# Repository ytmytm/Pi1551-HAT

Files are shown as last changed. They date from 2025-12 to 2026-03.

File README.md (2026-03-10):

# PI1551 HAT

A minimalistic HAT for Raspberry Pi 3A/3B/3B+ that gives you low-cost **1551 floppy emulation** (and optionally **TAP tape playback**) for Commodore C16/C116 or Plus/4. You build only what you need: the core is a few parts; display, controls, and TAP support are optional add-ons.

**Warning: For [tcbm2sd](https://github.com/ytmytm/plus4-tcbm2sd) ONLY. Do not connect this HAT to a real 1551 drive. The circuit is not 5V-tolerant and can damage the Raspberry Pi.**

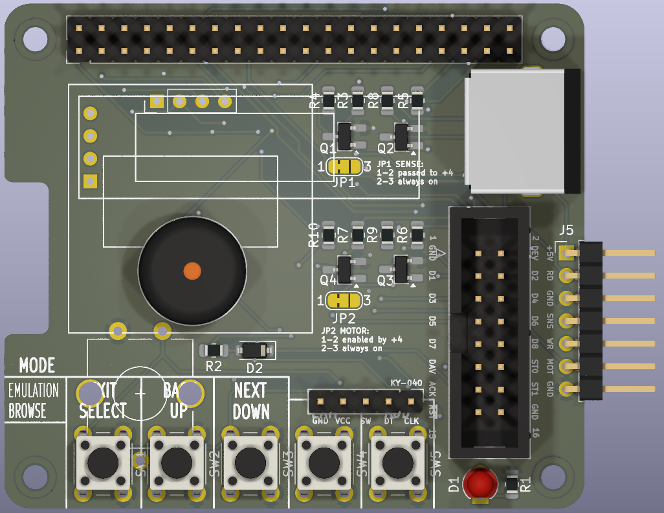
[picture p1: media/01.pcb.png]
PI1551 HAT PCB


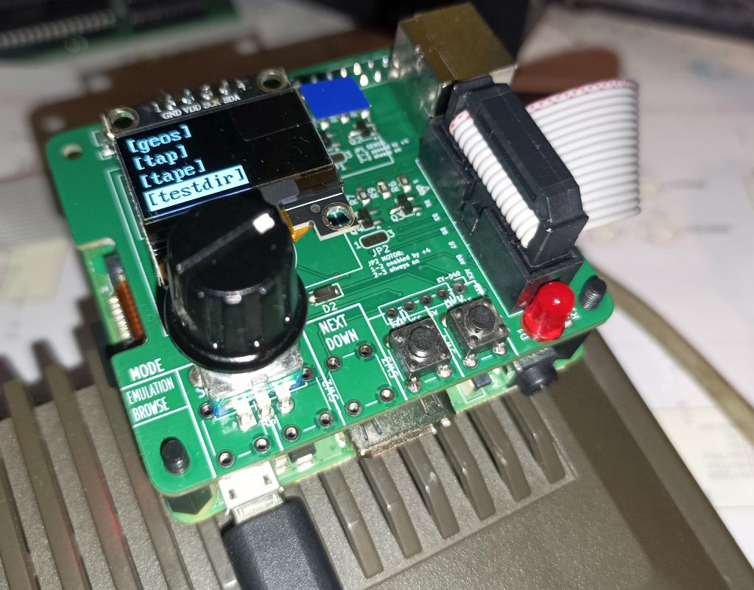
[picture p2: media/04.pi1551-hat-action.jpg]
PI1551-HAT in action


---

## What to build (at a glance)

This is a HAT board that sits on top of a Raspberry Pi. You need to have a Raspberry Pi 3A or 3B and a capable (at least 2A) USB-Micro power supplier for it.

| Goal | You need |
|---|---|
| **1551 emulation only** | PCB + required parts below + 16-wire ribbon cable + [tcbm2sd](https://github.com/ytmytm/plus4-tcbm2sd). No display, no buttons (disk commands only or HDMI+USB keyboard). |
| **1551 + menu on device** | Above + **one of**: 5 buttons, or 2 buttons + rotary encoder (ALPS EC11E or KY-040). Optionally add OLED and/or LED. |
| **1551 + TAP playback** | Above + TAP_READ block (Q2, R5, R8) + MiniDIN-7 socket or J5 header + cable to computer. Rest of TAP circuit is optional but recommended (see [TAP playback](#tap-playback)). |

Everything not in the “required parts” list is optional. You can add options later.

---

## Origin

Cloned from [PI1541 Hat](https://github.com/tebl/C64-Pi1541-module), adapted for 1551 and tape playback.

## Software

Firmware: [Pi1551](https://github.com/ytmytm/Pi1551) (branch `pi1551`).

## Hardware

The [Releases](https://github.com/ytmytm/Pi1551-HAT/releases) section contains all the files you need for manufacturing the PCB with SMD parts populated. That includes Gerber files, BOM with JLCPCB part numbers and SMD part positions.

- [Schematic PDF](plots/RPi_Hat.pdf)
- [Gerbers](plots/)

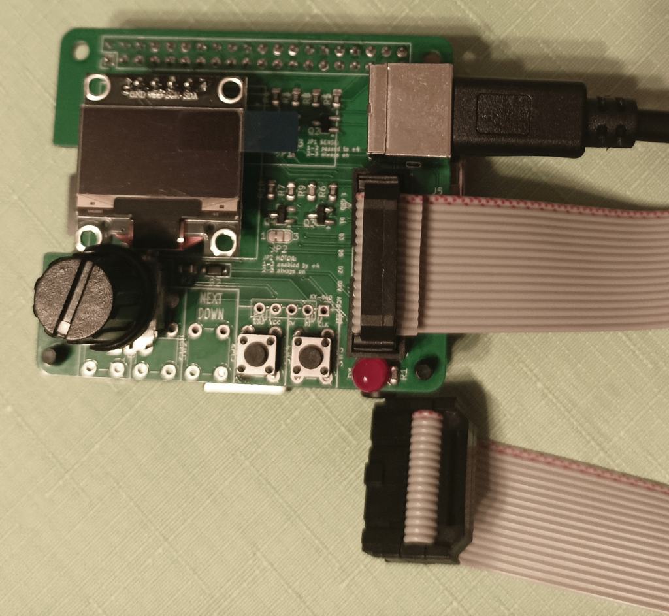
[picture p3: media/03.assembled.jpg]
PI1551 HAT fully assembled


### Required parts (1551 emulation)

- 40×2 female header for Raspberry Pi GPIO
- 2×8 (16-pin) male IDC connector for ribbon cable to [tcbm2sd](https://github.com/ytmytm/plus4-tcbm2sd)
- D2: Schottky diode (BAT54, BAS40, BAT43 or 1N5819) — protects the Pi
- R2: 10K resistor (with D2)
- R11-23: 13×10K resistors (TCBM pullups)

Plus a **straight 16-wire ribbon cable**. Connections are 1:1; both ends must be crimped the same way. I recommend crimping the cable the same way as in the photo above, with both connectors identical — it makes cable routing easier on both ends.

You can order the PCB with SMD parts pre-populated:

<a href="https://www.pcbway.com/project/shareproject/PI1551_HAT_a7817d89.html">PCB from PCBWay</a>

### Optional: display

- OLED: SSD1306 128×64 or 128×32, or SH1106 128×64 (SH1106 is large - there is no room for rotary encoder, use 5 buttons instead).
- Pinout selectable by solder jumpers: GND/VCC/SCL/SCL (default) or VCC/GND/SCL/SCL.

### Optional: drive LED

- 3 mm or 5 mm LED + R1 (e.g. 220 Ω).

### Optional: audio

- 3 V buzzer with built-in oscillator.

### Optional: controls (pick one set)

- **Option A:** 5× 6×6 mm tact switches (SW1–SW5).
- **Option B:** 2× 6×6 mm tact switches (SW4-SW5) + rotary encoder (ALPS EC11E or a KY-040 module).

### TAP playback

To play TAP files you need:

- **TAP_READ block:** Q2, R5, R8 (required for tape in).
- **Connector:** MiniDIN-7 socket (J4) **or** 1×7 pin header (J5) to solder the cable.
- **Cable:** At least TAP_READ and GND; one end must be Mini-DIN-7 male.

A MiniDin-7 cable from Aliexpress may not fit Plus/4 cassette port because the squared plug won't fit the round hole in Plus/4 case. Just shave off the corners to make it more round. It may not look pretty, but it will work. 

If you intend to solder the cable yourself, the order of signals on J5 is such that it's easy to solder a piece of ribbon cable to a Mini-DIN-7 plug by going around the perimeter (see schematic for both pinouts). 

The rest of the TAP circuit is optional, but recommended:

- **TAP_SENSE** (Q1, R3, R4): lets the computer see “tape PLAY pressed”. If you omit it, close jumper JP1 so SENSE is always active.
- **MOTOR** (Q4, R7, R10): lets the computer control motor line. If you omit it, close JP2 so motor is always enabled (fine for Pi1551).

You can also leave all parts in and configure behaviour in the [Pi1551](https://github.com/ytmytm/Pi1551) config.

*If your Plus/4 has a 6510 CPU swap, it cannot drive the MOTOR line (see [this note](https://hackjunk.com/2017/06/23/commodore-16-plus-4-8501-to-6510-cpu-conversion/)). You can still have MOTOR active all the time via the [Pi1551](https://github.com/ytmytm/Pi1551) configuration file.*

**TAP_WRITE** (Q3, R6, R9) is on the PCB for future use when Pi1551 supports tape write.

## PCB

The board is a mixture of THT and SMD parts.

Don't be afraid of SMD parts, I have used larger footprints that are more friendly for hand soldering. You need tweezers, a steady hand, iron with a fine tip and a 0.5mm solder. Use the flux generously.

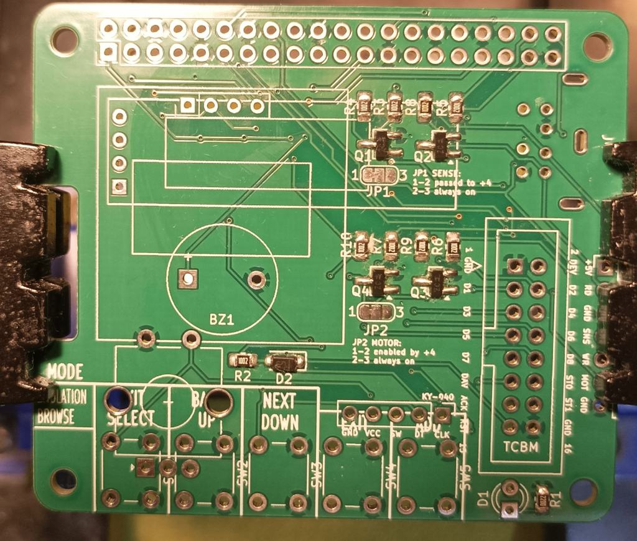
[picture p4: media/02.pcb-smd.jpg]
PI1551 HAT PCB with SMD parts assembled


Note the D2 diode orientation - the stripe is on the same side as the closed silkscreen, towards the TCBM connector. 

For convenience, the majority of resistors (R2-R23) are all the same. Use any value in the 1K-10K range you have at hand.

You might find that soldering those four SMD transistors, ten resistors and one diode is faster than their THT counterparts.

## BOM

Count of optional parts in brackets.

| Reference | Item | Count |
| --- | --- | ----- |
| J1 | 2x20 pin long female header | 1 |
| J2 | 2x8 pin IDC 16P socket | 1 |
| J3 | KY-040 rotary encoder module | (1)|
| J4 | MiniDIN-7 female socket | (1)|
| J5 | 1x7 pin long male header | (1)|
| BZ1 | Buzzer (5mm / 7mm pin spacing), 3V | (1)|
| IC1 | SSD1306 OLED-display 128x64 (0.96") | (1)|
| IC2 | SSD1306 OLED-display 128x32 (0.91") | (1)|
| SW1-SW5 | Momentary push button, 6x6mm | (5)|
| SW6 | ALPS EC11E rotary encoder or similar | (1)|
| D1 | 3mm / 5mm LED (e.g. red for authenticity) | (1)|
| D2 | Schottky diode: BAT54, 1n5819, BAT43, etc. | 1 |
| R1 | 100-220 Ohm (for LED) | (1)|
| R2-R23 | 1K-10K Ohm (R2 required; rest optional)|  14+(8)|
| Q1-Q4 | MMBT3904 / 2N3904 transistors | (4) |

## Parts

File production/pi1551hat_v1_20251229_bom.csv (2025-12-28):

Designator | Footprint | Quantity | Value | LCSC Part #
D2 | D_SOD-123 | 1 | BAT54 | C7502705
Q1, Q2, Q3, Q4 | SOT-23_Handsoldering | 4 | NPN: 2n3904 | C18536
R1 | 0805 | 1 | 220 | C17557
R10, R2, R3, R4, R5, R6, R7, R8, R9 | 0805 | 9 | 10k | C22356686

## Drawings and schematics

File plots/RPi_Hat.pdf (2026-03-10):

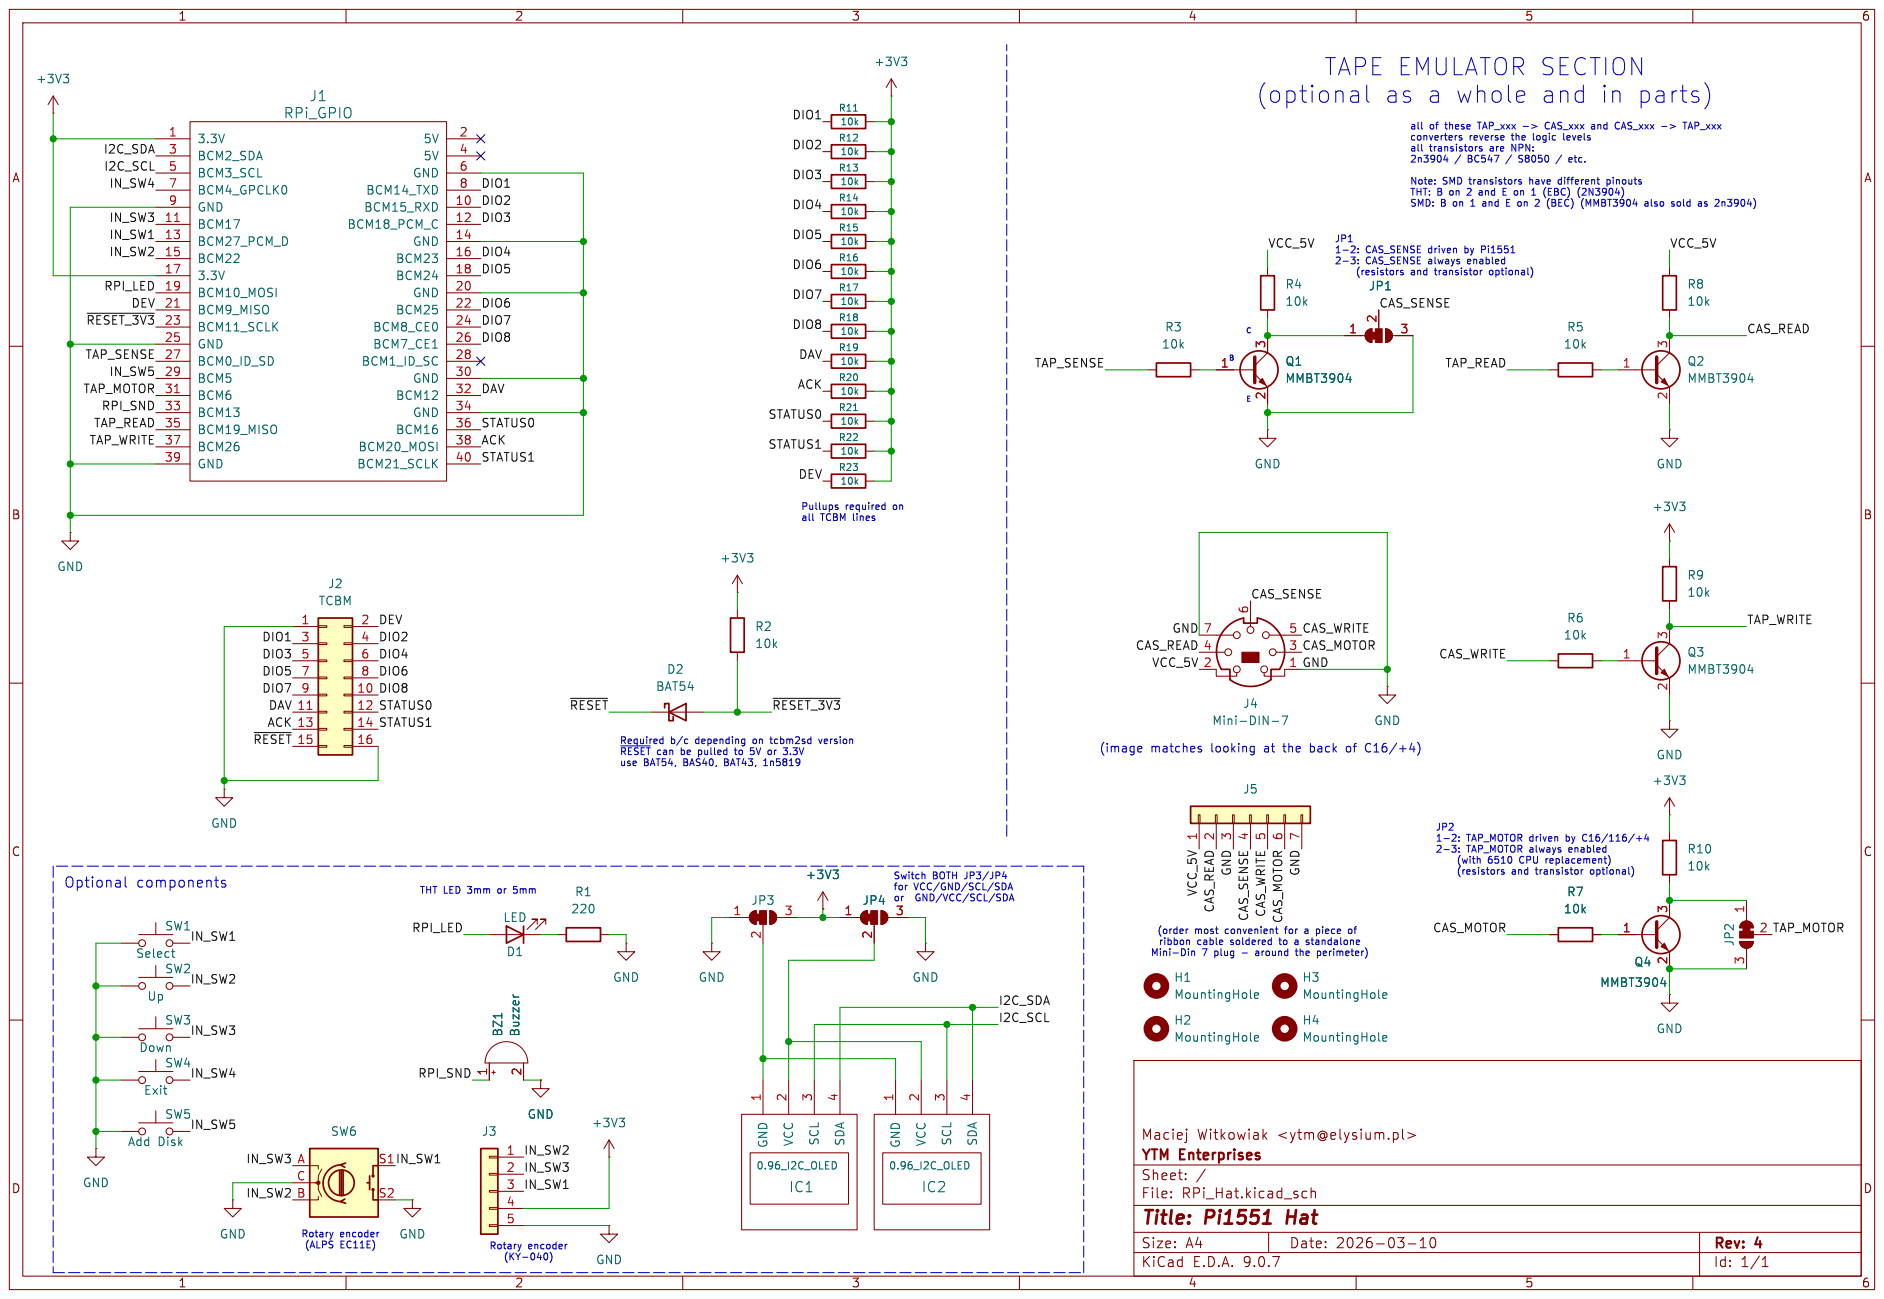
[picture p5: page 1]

(image matches looking at the back of C16/+4)

H3 MountingHole H4 MountingHole GND GND

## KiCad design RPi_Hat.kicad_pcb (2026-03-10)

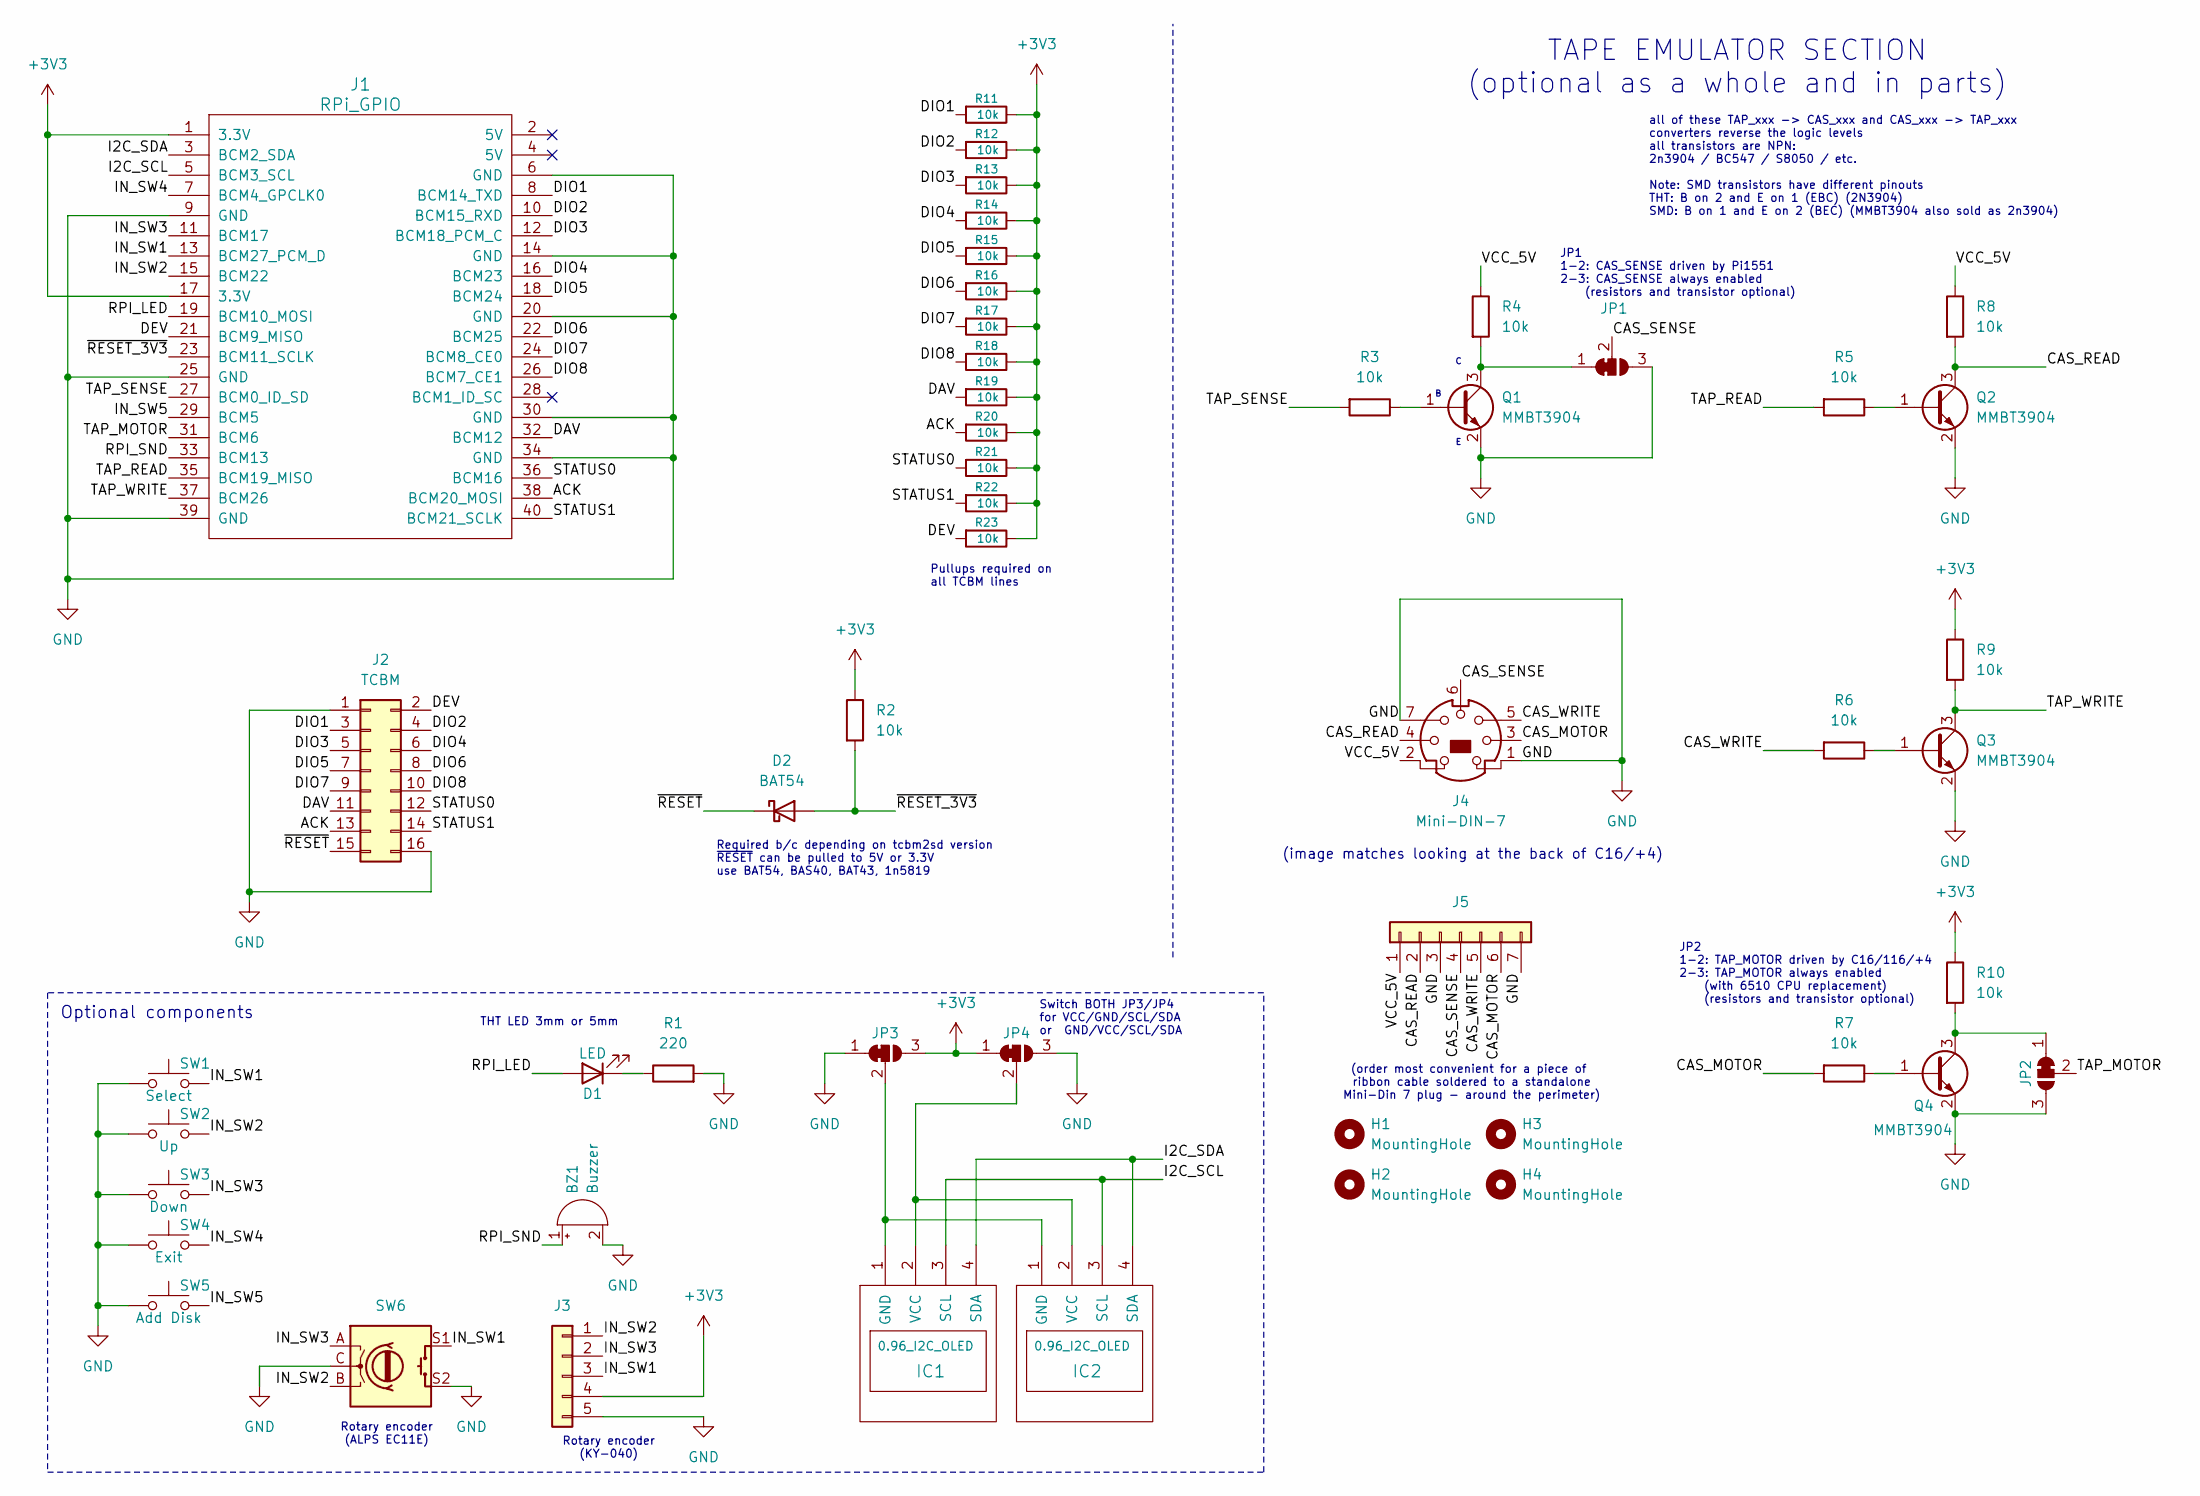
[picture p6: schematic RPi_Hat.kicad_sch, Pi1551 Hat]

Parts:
BZ1: Buzzer; Buzzer_12x9.5RM7.6
D1: LED; LED_D3.0mm
D2: BAT54; D_SOD-123; MFR.Part # BAT54W; JLCPCB Part # C7502705
H1, H2, H3, H4: MountingHole; MountingHole_2.7mm_M2.5_DIN965
IC1: 0.96_I2C_OLED; 0.91_I2C_OLED
IC2: 0.96_I2C_OLED
J1: RPi_GPIO; PinHeader_2x20_P2.54mm_Vertical
J2: TCBM; IDC-Header_2x08_P2.54mm_Vertical
J3: Conn_01x05; PinHeader_1x05_P2.54mm_Vertical
J4: Mini-DIN-7; Mini_DIN_round_7_canned
J5: Conn_01x07; PinHeader_1x07_P2.54mm_Horizontal
JP1, JP2, JP3, JP4: SolderJumper_3_Bridged12; SolderJumper-3_P1.3mm_Bridged12_RoundedPad1.0x1.5mm_NumberL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
Q1, Q2, Q3, Q4: MMBT3904; SOT-23_Handsoldering; MFR.Part # 2N3904S-RTK/PS; JLCPCB Part # C18536
R1: 220; R_0805_2012Metric_Pad1.20x1.40mm_HandSolder; MFR.Part # 0805W8F2200T5E; JLCPCB Part # C17557
R2, R3, R4, R5, R6, R7, R8, R9, R10, R11, R12, R13, R14, R15, R16, R17, R18, R19, R20, R21, R22, R23: 10k; R_0805_2012Metric_Pad1.20x1.40mm_HandSolder; MFR.Part # RCA0510KFLF; JLCPCB Part # C22356686
SW1: Select; SW_PUSH_6mm_H5mm
SW2: Up; SW_PUSH_6mm_H5mm
SW3: Down; SW_PUSH_6mm_H5mm
SW4: Exit; SW_PUSH_6mm_H5mm
SW5: Add Disk; SW_PUSH_6mm_H5mm
SW6: RotaryEncoder_Switch; RotaryEncoder_Alps_EC11E-Switch_Vertical_H20mm_CircularMoun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; MFR.Part # EC11E15244B2; JLCPCB Part # C470754

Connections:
+3V3: J1.1 (3.3V), J1.17 (3.3V), J3.4, JP3.3 (B), JP4.1 (A), R2.1, R9.1, R10.1, R11.1, R12.1, R13.1, R14.1, R15.1, R16.1, R17.1, R18.1, R19.1, R20.1, R21.1, R22.1, R23.1
/ACK: J1.38 (BCM20_MOSI), J2.13, R20.2
/CAS_MOTOR: J4.3, J5.6, R7.2
/CAS_READ: J4.4, J5.2, Q2.3 (C), R8.2
/CAS_SENSE: J4.6, J5.4, JP1.2 (C)
/CAS_WRITE: J4.5, J5.5, R6.2
/DAV: J1.32 (BCM12), J2.11, R19.2
/DEV: J1.21 (BCM9_MISO), J2.2, R23.2
/DIO1: J1.8 (BCM14_TXD), J2.3, R11.2
/DIO2: J1.10 (BCM15_RXD), J2.4, R12.2
/DIO3: J1.12 (BCM18_PCM_C), J2.5, R13.2
/DIO4: J1.16 (BCM23), J2.6, R14.2
/DIO5: J1.18 (BCM24), J2.7, R15.2
/DIO6: J1.22 (BCM25), J2.8, R16.2
/DIO7: J1.24 (BCM8_CE0), J2.9, R17.2
/DIO8: J1.26 (BCM7_CE1), J2.10, R18.2
/I2C_SCL: IC1.3 (SCL), IC2.3 (SCL), J1.5 (BCM3_SCL)
/I2C_SDA: IC1.4 (SDA), IC2.4 (SDA), J1.3 (BCM2_SDA)
/IN_SW1: J1.13 (BCM27_PCM_D), J3.3, SW1.2, SW6.S1
/IN_SW2: J1.15 (BCM22), J3.1, SW2.2, SW6.B
/IN_SW3: J1.11 (BCM17), J3.2, SW3.2, SW6.A
/IN_SW4: J1.7 (BCM4_GPCLK0), SW4.2
/IN_SW5: J1.29 (BCM5), SW5.2
/RPI_LED: D1.2 (A), J1.19 (BCM10_MOSI)
/RPI_SND: BZ1.1 (+), J1.33 (BCM13)
/STATUS0: J1.36 (BCM16), J2.12, R21.2
/STATUS1: J1.40 (BCM21_SCLK), J2.14, R22.2
/TAP_MOTOR: J1.31 (BCM6), JP2.2 (C)
/TAP_READ: J1.35 (BCM19_MISO), R5.2
/TAP_SENSE: J1.27 (BCM0_ID_SD), R3.2
/TAP_WRITE: J1.37 (BCM26), Q3.3 (C), R9.2
/VCC_5V: J4.2, J5.1, R4.1, R8.1
/~RESET_3V3: D2.2 (A), J1.23 (BCM11_SCLK), R2.2
/~RESET: D2.1 (K), J2.15
GND: BZ1.2 (-), J1.6 (GND), J1.9 (GND), J1.14 (GND), J1.20 (GND), J1.25 (GND), J1.30 (GND), J1.34 (GND), J1.39 (GND), J2.1, J2.16, J3.5, J4.1, J4.7, J5.3, J5.7, JP1.3 (B), JP2.3 (B), JP3.1 (A), JP4.3 (B), Q1.2 (E), Q2.2 (E), Q3.2 (E), Q4.2 (E), R1.2, SW1.1, SW2.1, SW3.1, SW4.1, SW5.1, SW6.C, SW6.S2
unnamed: D1.1 (K), R1.1
unnamed: IC1.1 (GND), IC2.1 (GND), JP3.2 (C)
unnamed: IC1.2 (VCC), IC2.2 (VCC), JP4.2 (C)
unnamed: JP1.1 (A), Q1.3 (C), R4.2
unnamed: JP2.1 (A), Q4.3 (C), R10.2
unnamed: Q1.1 (B), R3.1
unnamed: Q2.1 (B), R5.1
unnamed: Q3.1 (B), R6.1
unnamed: Q4.1 (B), R7.1

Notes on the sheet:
all of these TAP_xxx -> CAS_xxx and CAS_xxx -> TAP_xxx converters reverse the logic levels all transistors are NPN: 2n3904 / BC547 / S8050 / etc. Note: SMD transistors have different pinouts THT: B on 2 and E on 1 (EBC) (2N3904) SMD: B on 1 and E on 2 (BEC) (MMBT3904 also sold as 2n3904)
Optional components
JP2 1-2: TAP_MOTOR driven by C16/116/+4 2-3: TAP_MOTOR always enabled (with 6510 CPU replacement) (resistors and transistor optional)
TAPE EMULATOR SECTION (optional as a whole and in parts)
Rotary encoder (KY-040)
Rotary encoder (ALPS EC11E)
Pullups required on all TCBM lines
JP1 1-2: CAS_SENSE driven by Pi1551 2-3: CAS_SENSE always enabled (resistors and transistor optional)
THT LED 3mm or 5mm
(image matches looking at the back of C16/+4)
(order most convenient for a piece of ribbon cable soldered to a standalone Mini-Din 7 plug - around the perimeter)
Switch BOTH JP3/JP4 for VCC/GND/SCL/SDA or GND/VCC/SCL/SDA
Required b/c depending on tcbm2sd version ~{RESET} can be pulled to 5V or 3.3V use BAT54, BAS40, BAT43, 1n5819

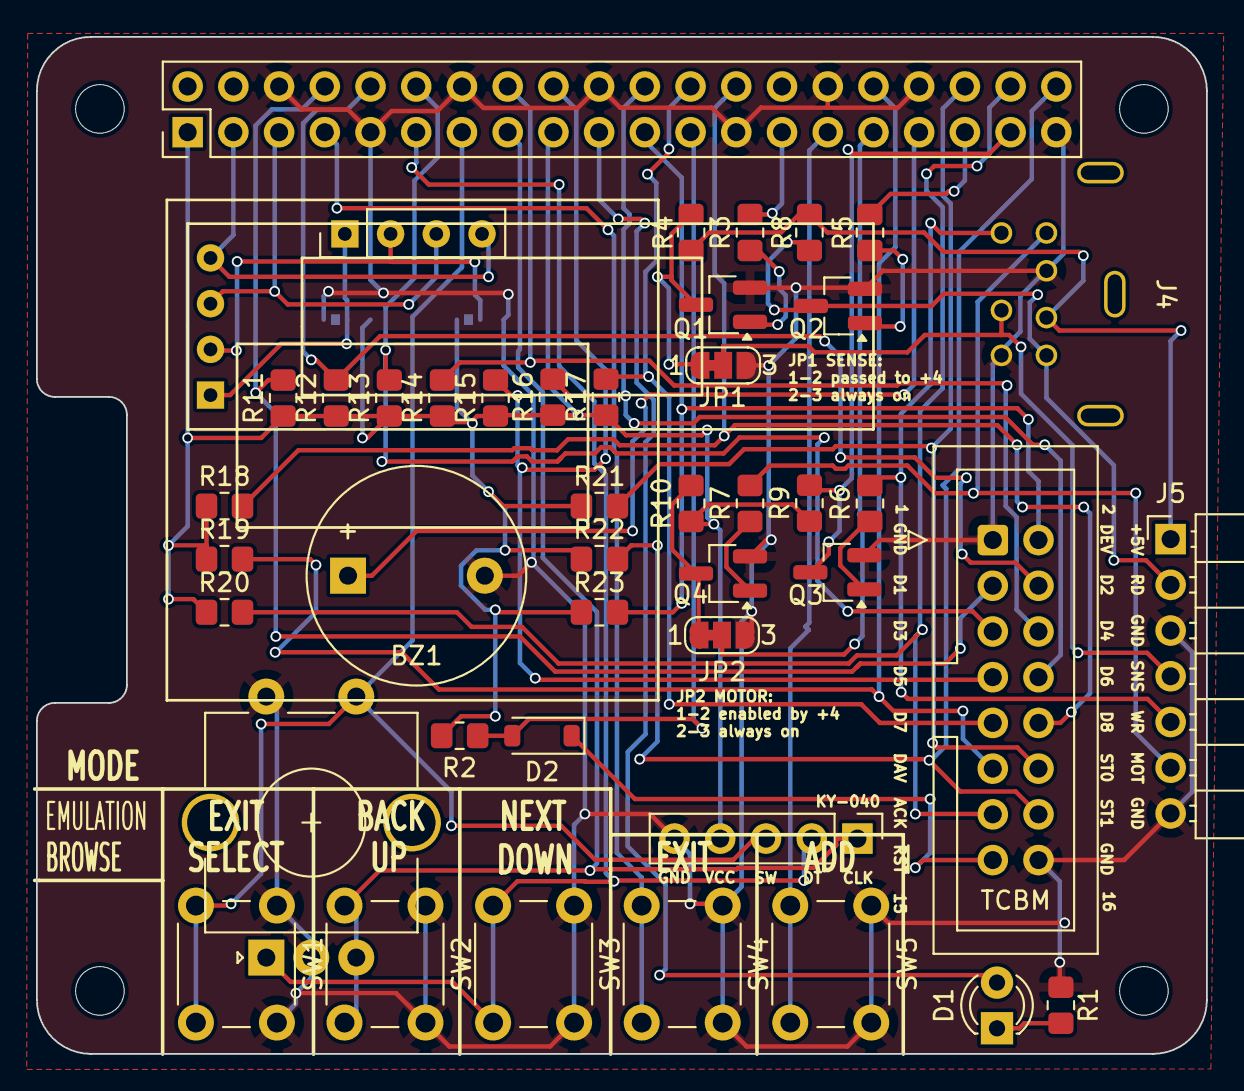
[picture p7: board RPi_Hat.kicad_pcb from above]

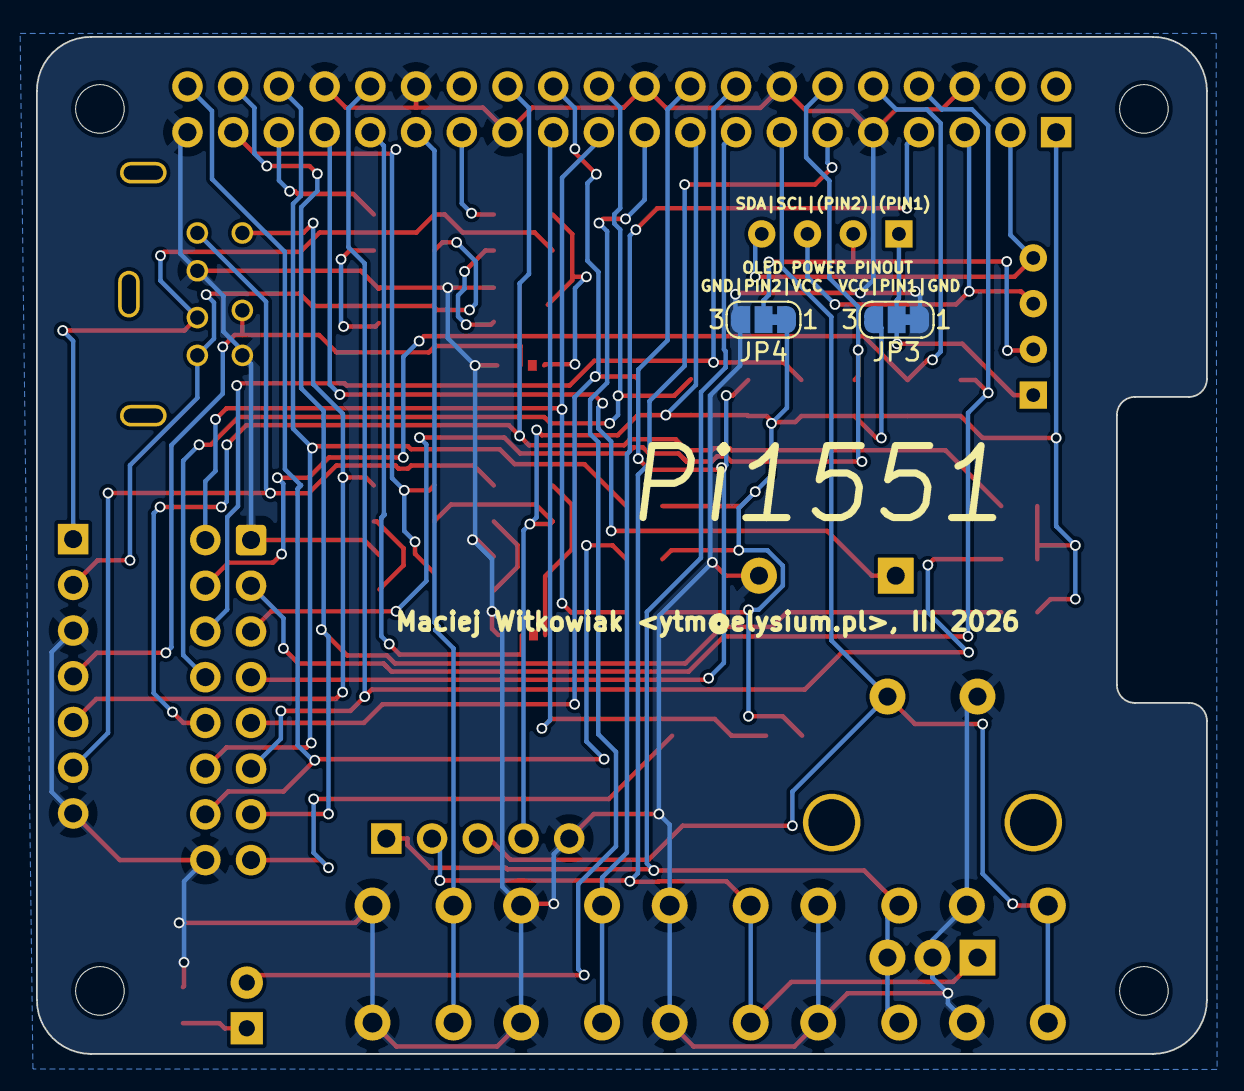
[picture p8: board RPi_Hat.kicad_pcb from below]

Board: 2 copper layers, 65.0 x 56.5 mm, 51 parts (2 on the bottom side), 44 nets.

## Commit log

2025-11-16 pi1551 hat, test version (20251022)
    [RPi_Hat-B_Cu.gbl, RPi_Hat-B_Mask.gbs, RPi_Hat-B_Paste.gbp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]
2025-11-16 exclusion zones and group TCBM connector silkscreen
    [RPi_Hat.kicad_pcb]
2025-12-07 /RESET voltage level protection, connector for rotary encoder, tape connector support
    [RPi_Hat.kicad_sch]
2025-12-14 completed tht version with tape interface support
    [RPi_Hat-B_Cu.gbl, RPi_Hat-B_Mask.gbs, RPi_Hat-B_Paste.gbp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]
2025-12-14 Conn_DIN_round parts from https://forum.kicad.info/t/mini-din-connectors-their-footprints-and-3-d-models-asking-for-discussion-and-a-bit-of-help-discussion/58247/11
2025-12-28 SMD rework and updates
    [RPi_Hat.kicad_pcb, RPi_Hat.kicad_sch]
2025-12-28 completed plots
    [RPi_Hat-B_Cu.gbl, RPi_Hat-B_Mask.gbs, RPi_Hat-B_Paste.gbp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]
2025-12-28 final version for test fabrication, added encoder part directly (without module, without pullups)
    [RPi_Hat-B_Cu.gbl, RPi_Hat-B_Mask.gbs, RPi_Hat-B_Paste.gbp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]
2026-02-01 - correct part and pinout for SMD 2n3904 transistor - added jumpers to configure VCC/GND routing for OLED screens - moved encoder to the left, module socket to the right
    [RPi_Hat-B_Cu.gbl, RPi_Hat-B_Mask.gbs, RPi_Hat-B_Paste.gbp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]
2026-02-01 remove Pi1551 Hat gerbers and media
    [RPi_Hat-B.Cu.gbl, RPi_Hat-B.Mask.gbs, RPi_Hat-B.Paste.gbp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]
2026-02-09 gerbers for fabrication
    [RPi_Hat-B_Cu.gbl, RPi_Hat-B_Mask.gbs, RPi_Hat-B_Paste.gbp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]
2026-02-27 Update
    Clarified ribbon cable instructions and updated component descriptions.
2026-02-27 Clarify
    Updated the recommendation for crimping the ribbon cable to clarify that both connectors should be done in the same way.
2026-03-08 Tape cable hint
2026-03-10 TCBM pullups are required
    [RPi_Hat-B_Cu.gbl, RPi_Hat-B_Mask.gbs, RPi_Hat-B_Paste.gbp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]
